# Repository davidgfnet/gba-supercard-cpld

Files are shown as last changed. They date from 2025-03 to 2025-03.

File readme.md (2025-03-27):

# GBA Supercard CPLD disassembly

CUPL-like equations for each macrocell can be found in the [report file](https://html-preview.github.io/?url=https://github.com/davidgfnet/gba-supercard-cpld/blob/master/report.html).

It would likely be much more understandable if readable signal/macrocell names were added based on which pins are hooked up to the GBA expansion bus and the various memory ICs.  There are comments in [main.zig](./main.zig) explaining how to specify these.  Afterwards, the report can be regenerated by running `zig build` from the repo directory.  This will require [Zig 0.14](https://ziglang.org/download/#release-0.14.0).

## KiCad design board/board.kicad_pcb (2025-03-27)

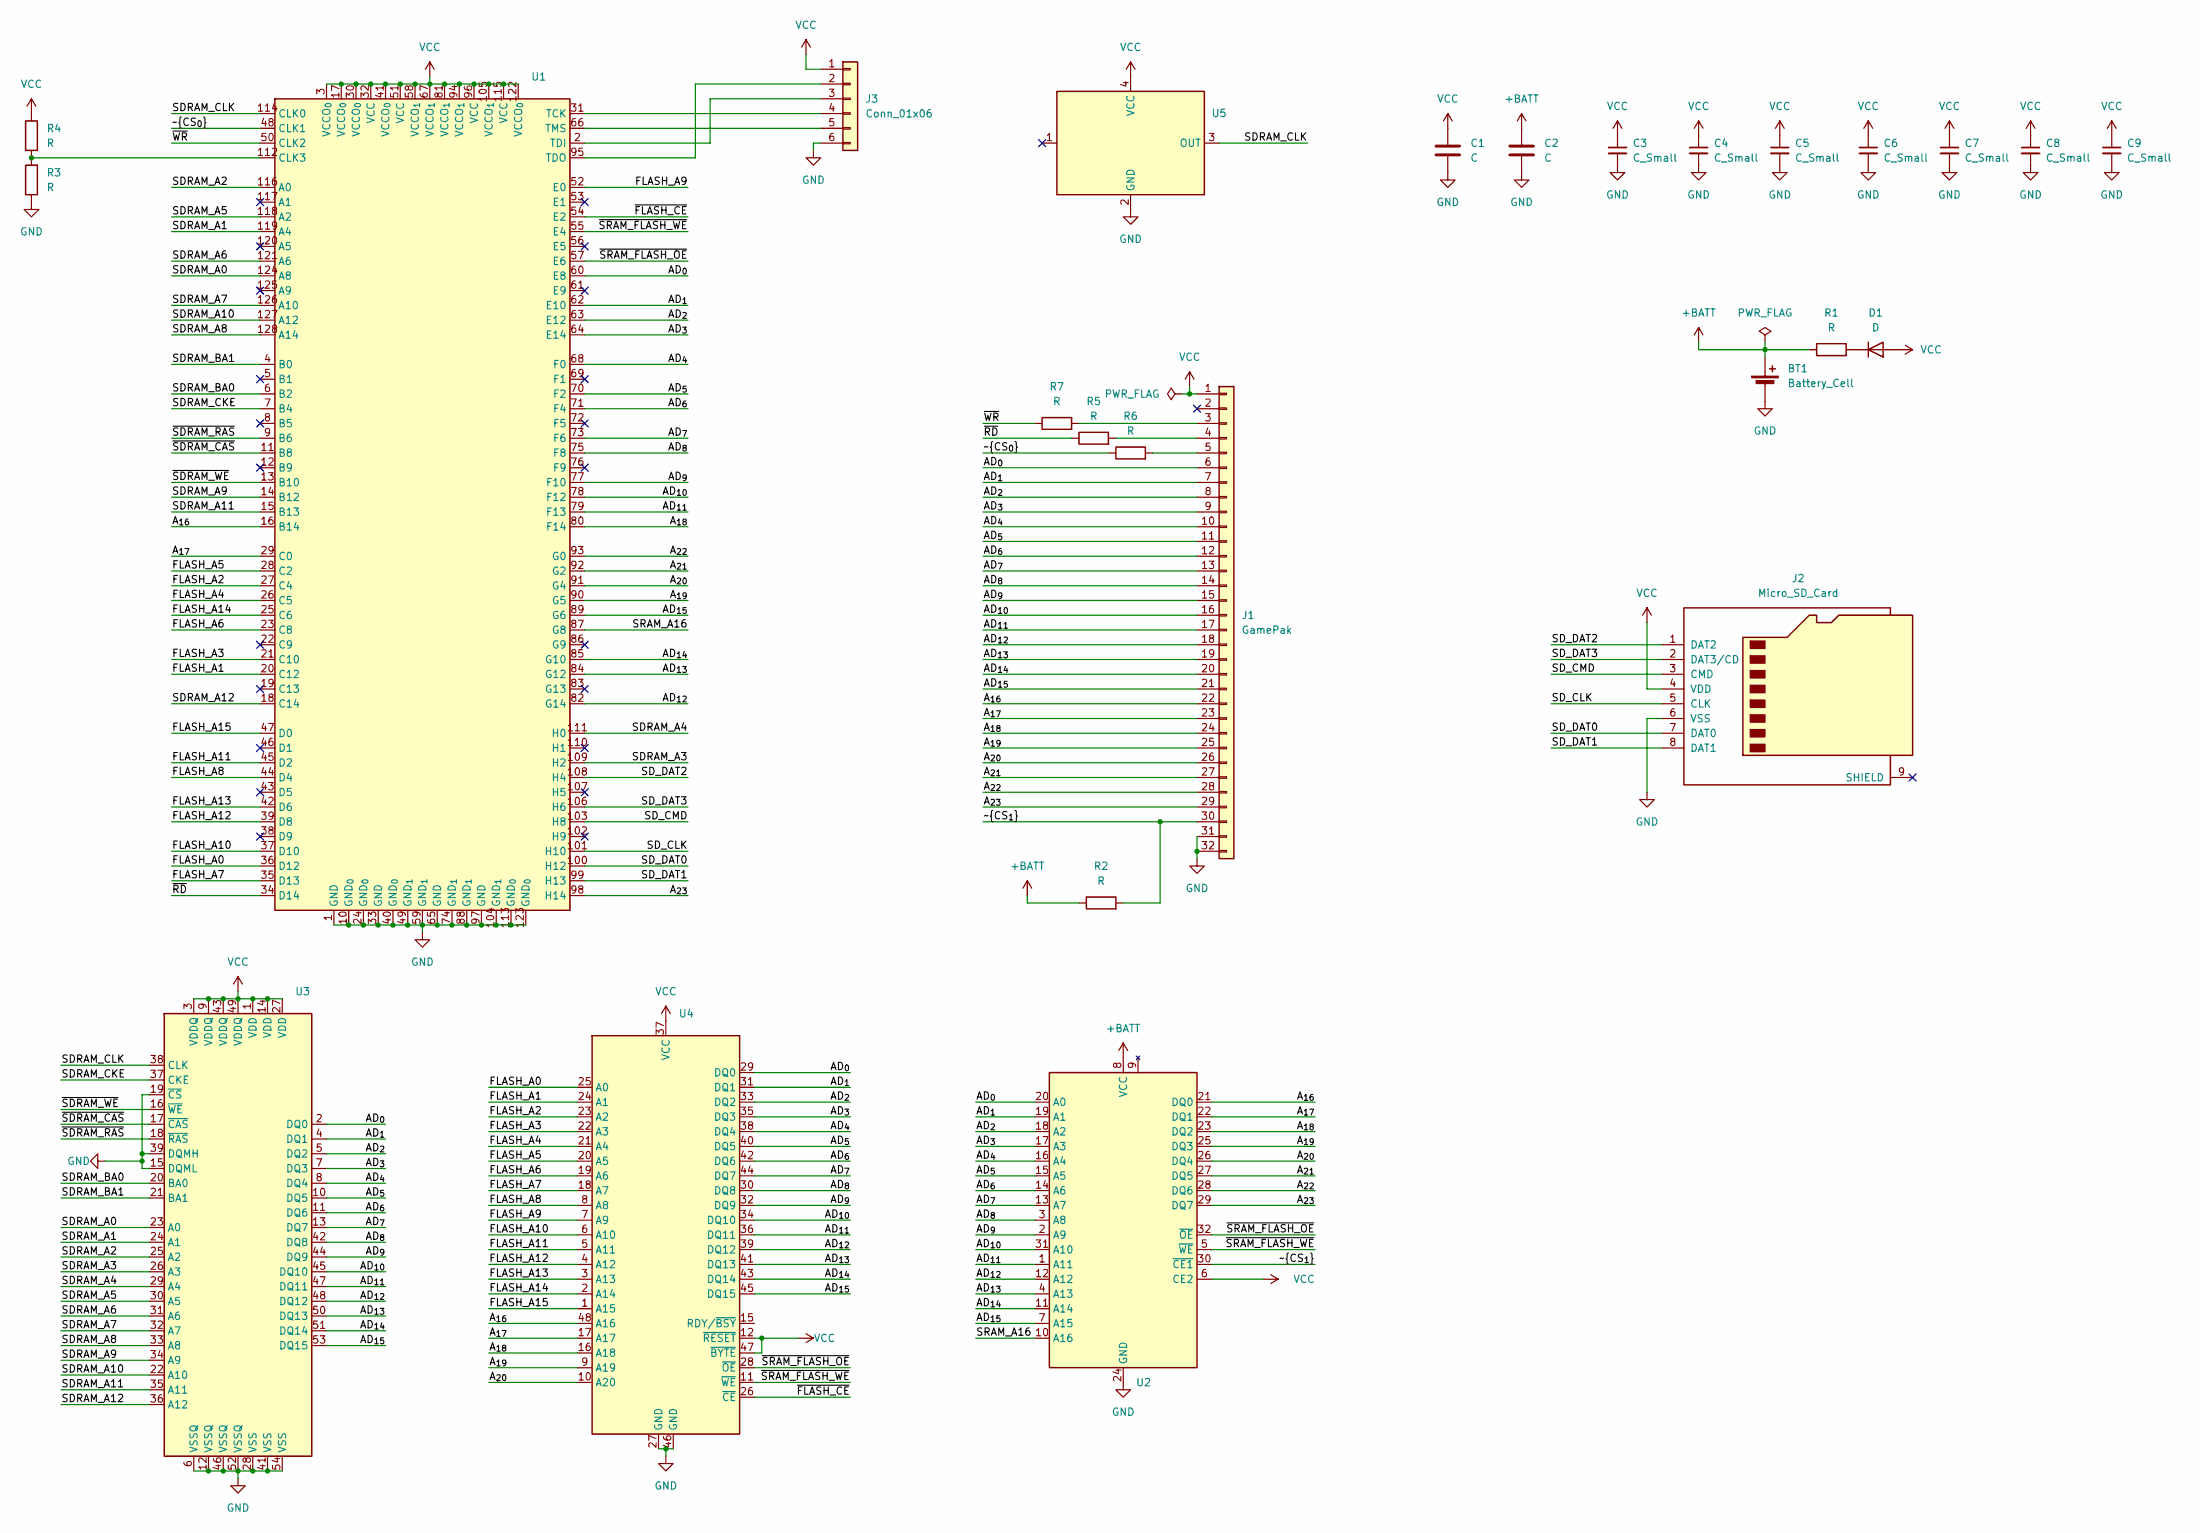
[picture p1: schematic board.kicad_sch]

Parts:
BT1: Battery_Cell; Battery
C1, C2: C; C_1206_3216Metric
C3, C4, C5, C6, C7, C8, C9: C_Small; C_0402_1005Metric
D1: D; D_SOD-323_HandSoldering
J1: GamePak; GamePak_CardEdge
J2: Micro_SD_Card; J_SD_Card-micro_socket_A
J3: Conn_01x06; JTAG
R1, R2, R3, R4, R5, R6, R7: R; R_0603_1608Metric
U1: TQFP-128_14x14mm_P0.4mm
U2: TSOP-I-32_11.8x8mm_P0.5mm
U3: TSOP-II-54_22.2x10.16mm_P0.8mm
U4: TSOP-I-48_18.4x12mm_P0.5mm
U5: Oscillator

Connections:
+BATT: BT1.1 (+), C2.1, R1.1, R2.1, U2.8 (VCC)
/AD_{0}: J1.6, U1.60 (E8), U2.20 (A0), U3.2 (DQ0), U4.29 (DQ0)
/AD_{1}: J1.7, U1.62 (E10), U2.19 (A1), U3.4 (DQ1), U4.31 (DQ1)
/AD_{2}: J1.8, U1.63 (E12), U2.18 (A2), U3.5 (DQ2), U4.33 (DQ2)
/AD_{3}: J1.9, U1.64 (E14), U2.17 (A3), U3.7 (DQ3), U4.35 (DQ3)
/AD_{4}: J1.10, U1.68 (F0), U2.16 (A4), U3.8 (DQ4), U4.38 (DQ4)
/AD_{5}: J1.11, U1.70 (F2), U2.15 (A5), U3.10 (DQ5), U4.40 (DQ5)
/AD_{6}: J1.12, U1.71 (F4), U2.14 (A6), U3.11 (DQ6), U4.42 (DQ6)
/AD_{7}: J1.13, U1.73 (F6), U2.13 (A7), U3.13 (DQ7), U4.44 (DQ7)
/AD_{8}: J1.14, U1.75 (F8), U2.3 (A8), U3.42 (DQ8), U4.30 (DQ8)
/AD_{9}: J1.15, U1.77 (F10), U2.2 (A9), U3.44 (DQ9), U4.32 (DQ9)
/AD_{10}: J1.16, U1.78 (F12), U2.31 (A10), U3.45 (DQ10), U4.34 (DQ10)
/AD_{11}: J1.17, U1.79 (F13), U2.1 (A11), U3.47 (DQ11), U4.36 (DQ11)
/AD_{12}: J1.18, U1.82 (G14), U2.12 (A12), U3.48 (DQ12), U4.39 (DQ12)
/AD_{13}: J1.19, U1.84 (G12), U2.4 (A13), U3.50 (DQ13), U4.41 (DQ13)
/AD_{14}: J1.20, U1.85 (G10), U2.11 (A14), U3.51 (DQ14), U4.43 (DQ14)
/AD_{15}: J1.21, U1.89 (G6), U2.7 (A15), U3.53 (DQ15), U4.45 (DQ15)
/A_{16}: J1.22, U1.16 (B14), U2.21 (DQ0), U4.48 (A16)
/A_{17}: J1.23, U1.29 (C0), U2.22 (DQ1), U4.17 (A17)
/A_{18}: J1.24, U1.80 (F14), U2.23 (DQ2), U4.16 (A18)
/A_{19}: J1.25, U1.90 (G5), U2.25 (DQ3), U4.9 (A19)
/A_{20}: J1.26, U1.91 (G4), U2.26 (DQ4), U4.10 (A20)
/A_{21}: J1.27, U1.92 (G2), U2.27 (DQ5)
/A_{22}: J1.28, U1.93 (G0), U2.28 (DQ6)
/A_{23}: J1.29, U1.98 (H14), U2.29 (DQ7)
/FLASH_A0: U1.36 (D12), U4.25 (A0)
/FLASH_A1: U1.20 (C12), U4.24 (A1)
/FLASH_A2: U1.27 (C4), U4.23 (A2)
/FLASH_A3: U1.21 (C10), U4.22 (A3)
/FLASH_A4: U1.26 (C5), U4.21 (A4)
/FLASH_A5: U1.28 (C2), U4.20 (A5)
/FLASH_A6: U1.23 (C8), U4.19 (A6)
/FLASH_A7: U1.35 (D13), U4.18 (A7)
/FLASH_A8: U1.44 (D4), U4.8 (A8)
/FLASH_A9: U1.52 (E0), U4.7 (A9)
/FLASH_A10: U1.37 (D10), U4.6 (A10)
/FLASH_A11: U1.45 (D2), U4.5 (A11)
/FLASH_A12: U1.39 (D8), U4.4 (A12)
/FLASH_A13: U1.42 (D6), U4.3 (A13)
/FLASH_A14: U1.25 (C6), U4.2 (A14)
/FLASH_A15: U1.47 (D0), U4.1 (A15)
/SDRAM_A0: U1.124 (A8), U3.23 (A0)
/SDRAM_A1: U1.119 (A4), U3.24 (A1)
/SDRAM_A2: U1.116 (A0), U3.25 (A2)
/SDRAM_A3: U1.109 (H2), U3.26 (A3)
/SDRAM_A4: U1.111 (H0), U3.29 (A4)
/SDRAM_A5: U1.118 (A2), U3.30 (A5)
/SDRAM_A6: U1.121 (A6), U3.31 (A6)
/SDRAM_A7: U1.126 (A10), U3.32 (A7)
/SDRAM_A8: U1.128 (A14), U3.33 (A8)
/SDRAM_A9: U1.14 (B12), U3.34 (A9)
/SDRAM_A10: U1.127 (A12), U3.22 (A10)
/SDRAM_A11: U1.15 (B13), U3.35 (A11)
/SDRAM_A12: U1.18 (C14), U3.36 (A12)
/SDRAM_BA0: U1.6 (B2), U3.20 (BA0)
/SDRAM_BA1: U1.4 (B0), U3.21 (BA1)
/SDRAM_CKE: U1.7 (B4), U3.37 (CKE)
/SDRAM_CLK: U1.114 (CLK0), U3.38 (CLK), U5.3 (OUT)
/SD_CLK: J2.5 (CLK), U1.101 (H10)
/SD_CMD: J2.3 (CMD), U1.103 (H8)
/SD_DAT0: J2.7 (DAT0), U1.100 (H12)
/SD_DAT1: J2.8 (DAT1), U1.99 (H13)
/SD_DAT2: J2.1 (DAT2), U1.108 (H4)
/SD_DAT3: J2.2 (DAT3/CD), U1.106 (H6)
/SRAM_A16: U1.87 (G8), U2.10 (A16)
/~CS_{0}: R6.1, U1.48 (CLK1)
/~CS_{1}: J1.30, R2.2, U2.30 (~CE1)
/~FLASH_CE: U1.54 (E2), U4.26 (~CE)
/~RD: R5.1, U1.34 (D14)
/~SDRAM_CAS: U1.11 (B8), U3.17 (~CAS)
/~SDRAM_RAS: U1.9 (B6), U3.18 (~RAS)
/~SDRAM_WE: U1.13 (B10), U3.16 (~WE)
/~SRAM_FLASH_OE: U1.57 (E6), U2.32 (~OE), U4.28 (~OE)
/~SRAM_FLASH_WE: U1.55 (E4), U2.5 (~WE), U4.11 (~WE)
/~WR: R7.1, U1.50 (CLK2)
GND: BT1.2 (-), C1.2, C2.2, C3.2, C4.2, C5.2, C6.2, C7.2, C8.2, C9.2, J1.31, J1.32, J2.6 (VSS), J3.6, R3.1, U1.1 (GND), U1.10 (GND_{0}), U1.24 (GND_{0}), U1.33 (GND), U1.40 (GND_{0}), U1.49 (GND_{1}), U1.59 (GND_{1}), U1.65 (GND), U1.74 (GND_{1}), U1.88 (GND_{1}), U1.97 (GND), U1.104 (GND_{1}), U1.113 (GND_{0}), U1.123 (GND_{0}), U2.24 (GND), U3.6 (VSSQ), U3.12 (VSSQ), U3.15 (DQML), U3.19 (~CS), U3.28 (VSS), U3.39 (DQMH), U3.41 (VSS), U3.46 (VSSQ), U3.52 (VSSQ), U3.54 (VSS), U4.27 (GND), U4.46 (GND), U5.2 (GND)
unnamed: D1.1 (K), R1.2
unnamed: J1.3, R7.2
unnamed: J1.4, R5.2
unnamed: J1.5, R6.2
unnamed: J3.2, U1.95 (TDO)
unnamed: J3.3, U1.2 (TDI)
unnamed: J3.4, U1.31 (TCK)
unnamed: J3.5, U1.66 (TMS)
unnamed: R3.2, R4.2, U1.112 (CLK3)
VCC: C1.1, C3.1, C4.1, C5.1, C6.1, C7.1, C8.1, C9.1, D1.2 (A), J1.1, J2.4 (VDD), J3.1, R4.1, U1.3 (VCCO_{0}), U1.17 (VCCO_{0}), U1.30 (VCCO_{0}), U1.32 (VCC), U1.41 (VCCO_{0}), U1.51 (VCC), U1.58 (VCCO_{1}), U1.67 (VCCO_{1}), U1.81 (VCCO_{1}), U1.94 (VCCO_{1}), U1.96 (VCC), U1.105 (VCCO_{1}), U1.115 (VCC), U1.122 (VCCO_{0}), U2.6 (CE2), U3.1 (VDD), U3.3 (VDDQ), U3.9 (VDDQ), U3.14 (VDD), U3.27 (VDD), U3.43 (VDDQ), U3.49 (VDDQ), U4.12 (~RESET), U4.37 (VCC), U4.47 (~BYTE), U5.4 (VCC)

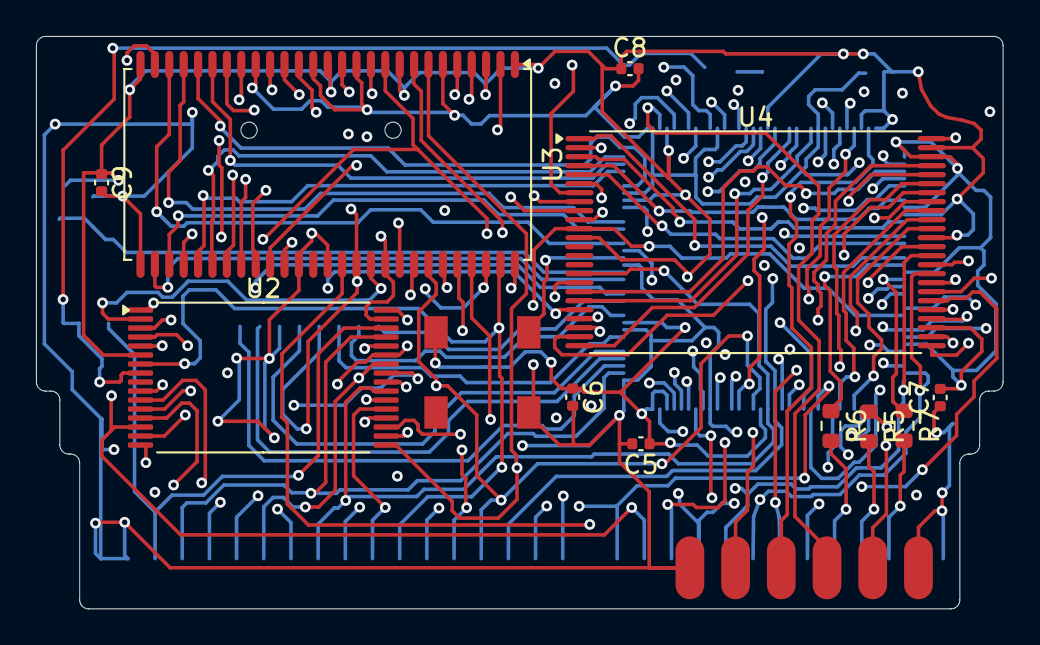
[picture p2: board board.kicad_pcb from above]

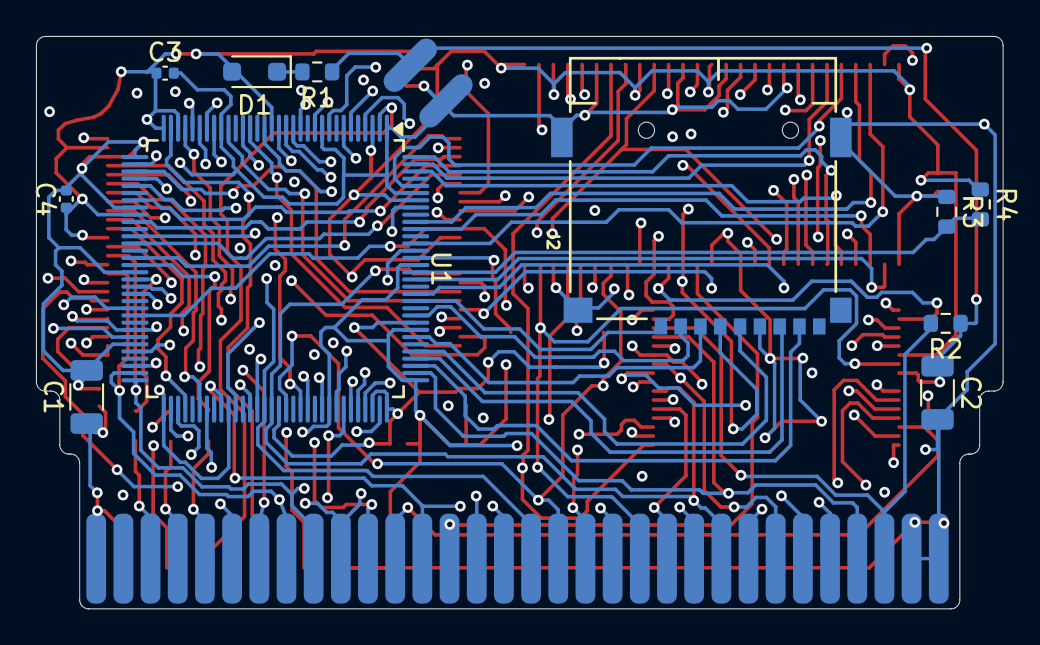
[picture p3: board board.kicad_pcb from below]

Board: 4 copper layers, 53.7 x 31.8 mm, 26 parts (13 on the bottom side), 86 nets.
